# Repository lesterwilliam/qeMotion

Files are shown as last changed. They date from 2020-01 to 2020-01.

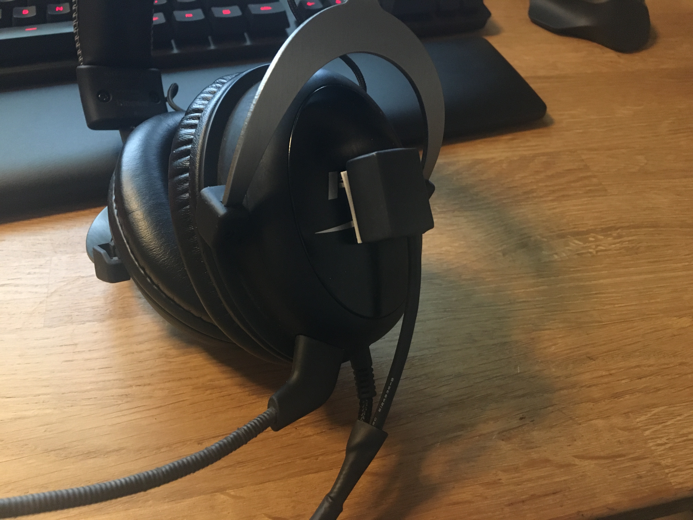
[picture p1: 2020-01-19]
media/Sensor/Sensor mounted 1.JPG

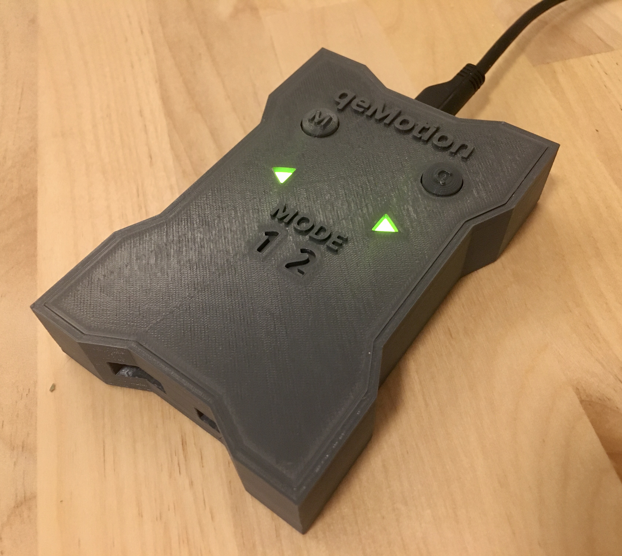
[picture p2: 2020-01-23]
media/Complete/qeMotion complete 1.JPG

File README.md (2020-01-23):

# qeMotion

## Introduction
This project originated from my need make leaning in first-person-shooter games easier. Games that enable you to lean around corners to peak or take a shot with giving the enemy the smallest possible target, like PlayerUnknown Battleground or Tom Clancy's Six Siege usually implemet leaning with the keyboard keys 'Q' and 'E'. While it is quite the obvious choice to use the keys close to the usual movement-keys 'W'/'A'/'S'/'D', it is quite hard to use if you need to crouch, move and lean at the same time. There just aren't enough fingers.
My idea to the problem was to implement a simple device that tracks my head motion to trigger and hold the respective lean movement.

## Hardware
I tried to keep stuff simple. The essential two parts for this project are the Arduino Pro Micro and an MPU6050 Gyro-/Accelerometer unit. You can use other Arduino boards, but it has to have USB support. The ATmega32u4 does that, which is found of the Arduino Leonardo too for example.
In my implementation are two buttons, two LED to show the virtual press of the 'Q'/'E' keys and four LEDs to show a mode. The LEDs are controlled via bipolar Transistors, either high- or low-side switches. This might not be of importance, I wasn't sure if the Arduino pins can deliver that much current. If you decide to use low-current LEDs you should be fine with driving them directly from the Arduino.
The MPU6050 sensor unit is fixed to the headset, while the Arduino sits on my desk. I went for this approach to minimize weight on my head. Since sensor and Arduino communicate via I2C, which is not meant to be used over such distances, I used an old USB cable which at least has some sort of shielding. Don't know if this was necessairy, but it seems to work perfectly with a cable length of 1.2m (4ft).

## Software
To make development easier and usage more versatile I've implemented multiple modes for the device. Only two of which are actually in use right now, one of which does exactly nothing, and the other is my first try at motion tracking (which works to some degree).
The usual loop() function calls subfunctions in defined time intervals, which can be tuned in the #defines.

This whole software is not nearly perfect nor finished. But I've tried to design it in a way it is the easiest to understand and modify to someones needs. If you struggle to understand it's structure and thoughts behind it, feel free to ask me anything. I'd be glad to help!

## Case
I've designed a 3d-printable case for the device. This may not suit you and your PCB layout, but I'll try to add some photos of my PCB for reference.
There is also a secondary case which doesn't really have to do anything with this sensor. But since my headset (HyperX Cloud 2) has this remote near where the Arduino will sit, I've designed a case that snaps those two together nicely (MAGNETS!!).

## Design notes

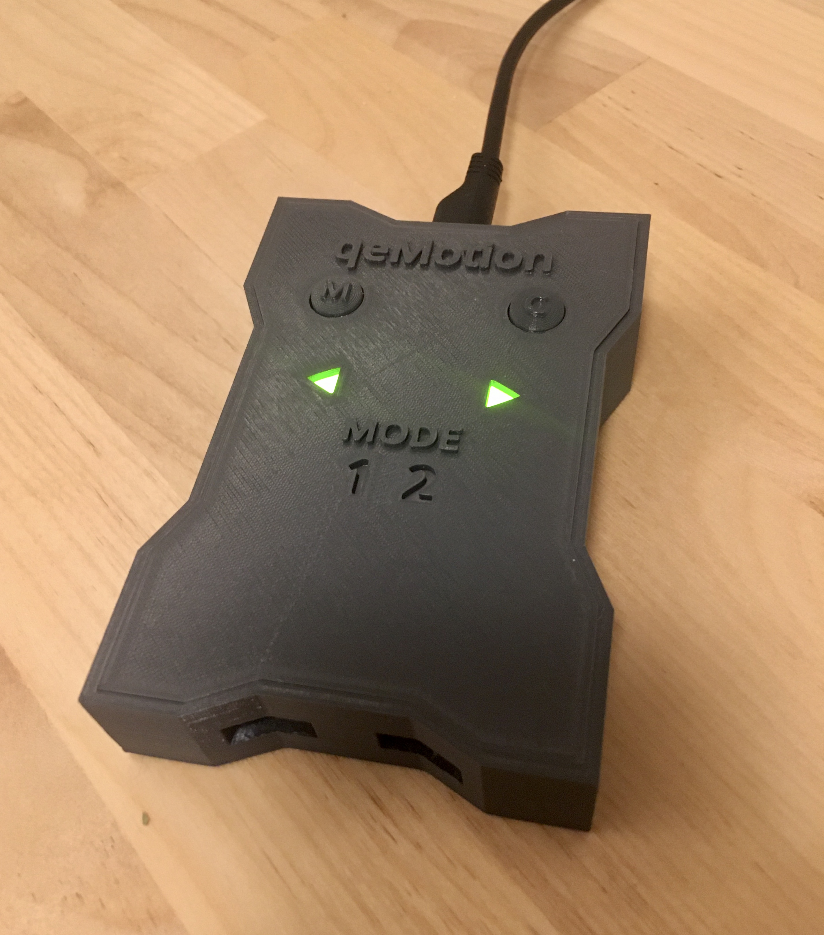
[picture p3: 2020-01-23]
media/Complete/qeMotion complete 2.JPG

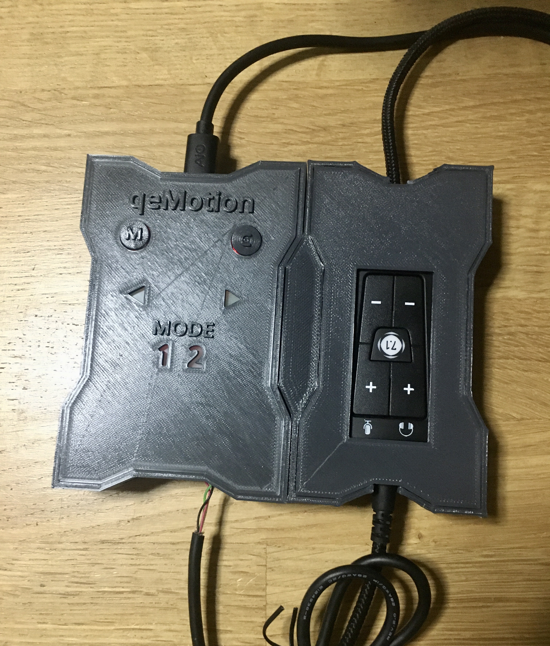
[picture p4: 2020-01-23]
media/Complete/qeMotion with HyperX Addon 4.JPG

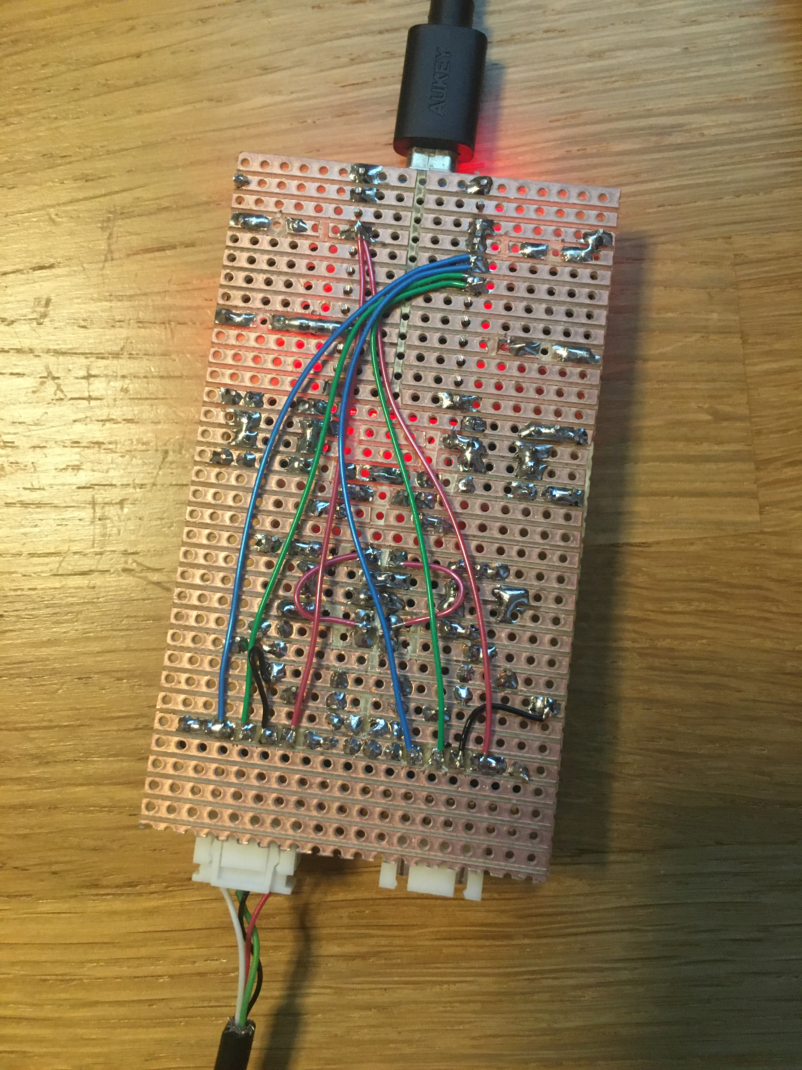
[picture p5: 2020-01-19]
media/PCB/PCB back.JPG

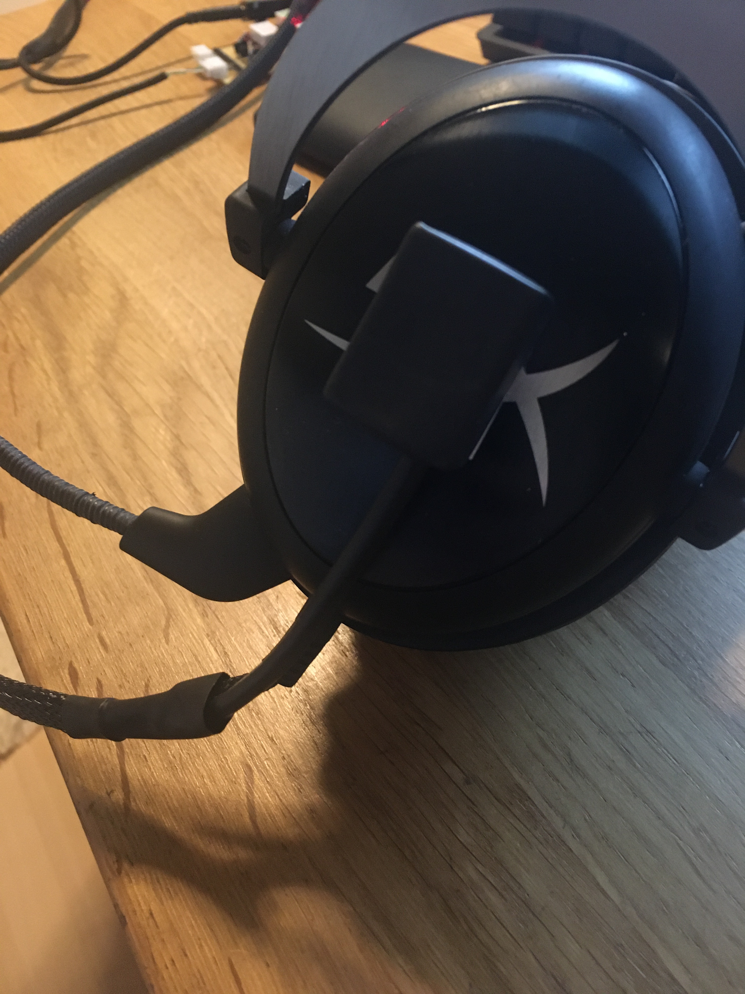
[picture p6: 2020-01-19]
media/Sensor/Sensor mounted 2.JPG

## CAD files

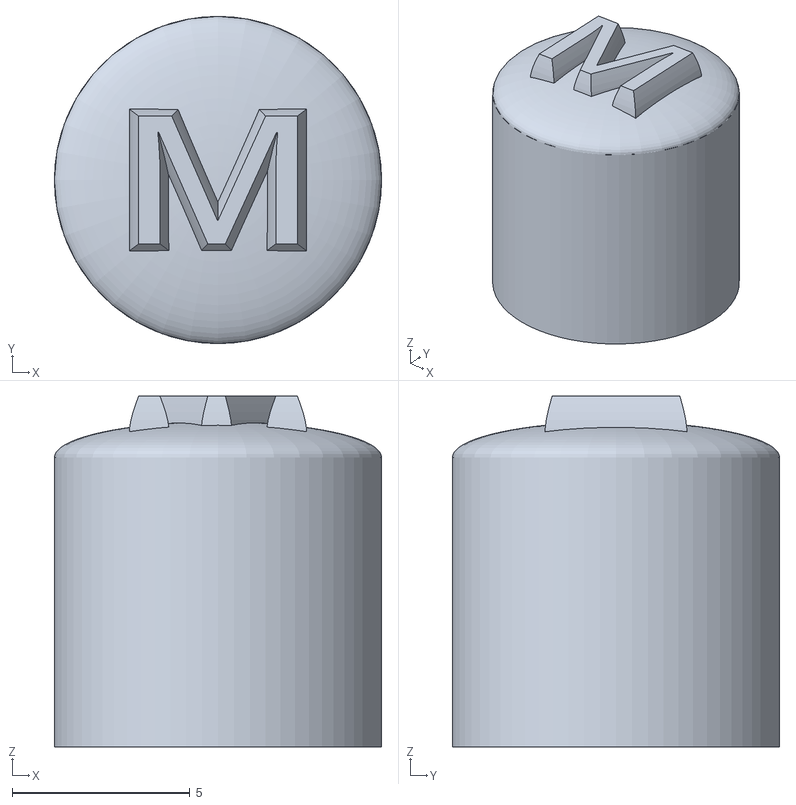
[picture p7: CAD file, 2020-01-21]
3D/Controller/qeMotion Button mode.stl
9.20 x 9.20 x 9.87

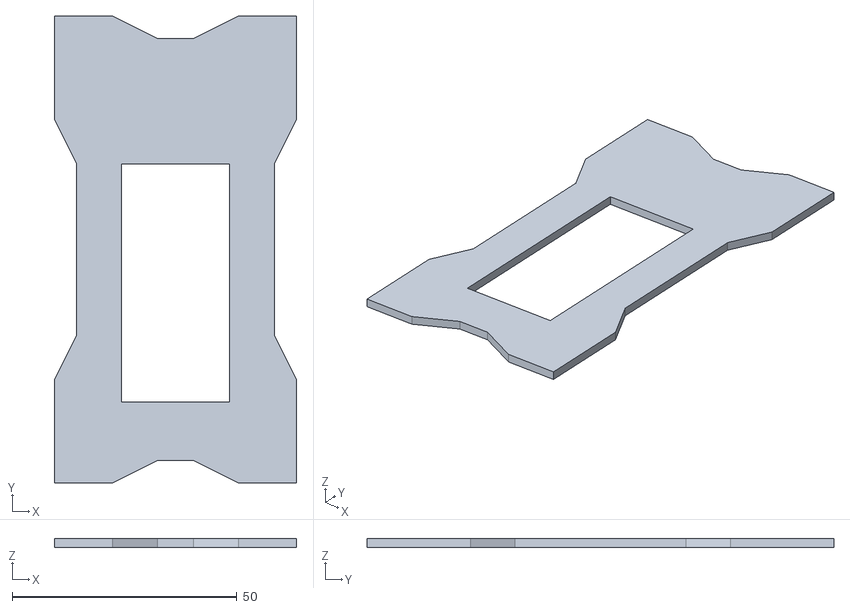
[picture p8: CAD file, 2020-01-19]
3D/HyperX Cloud 2 Headset Addon/qeMotion HyperX Cloud Addon upper.stl
54.0 x 104.0 x 2.00

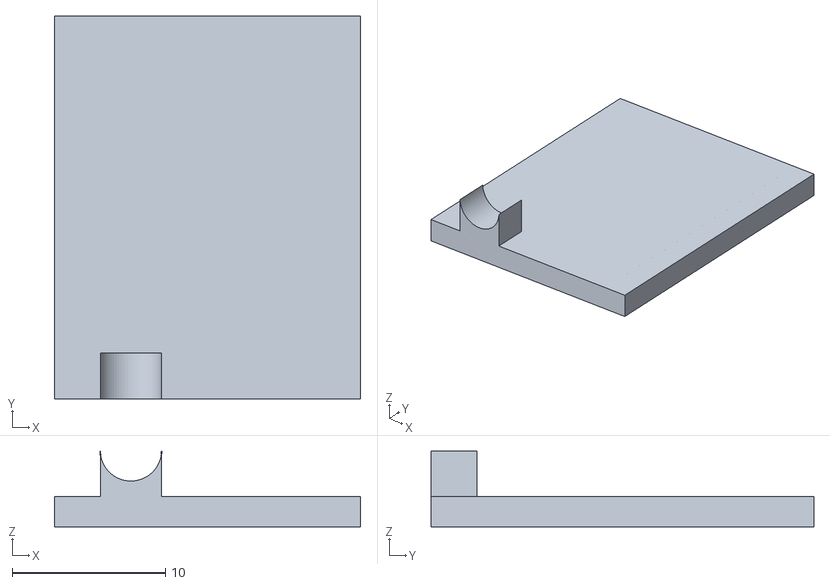
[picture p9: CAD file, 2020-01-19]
3D/Sensor/qeMotion Sensor lower.stl
20.0 x 25.0 x 4.96

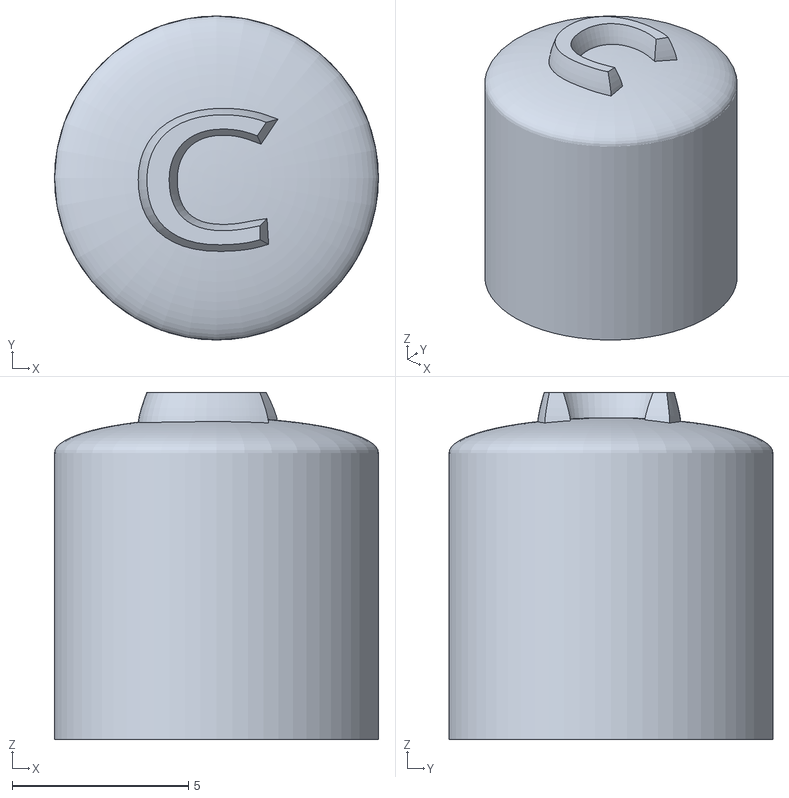
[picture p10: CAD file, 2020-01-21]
3D/Controller/qeMotion Button calibration.stl
9.20 x 9.20 x 9.87

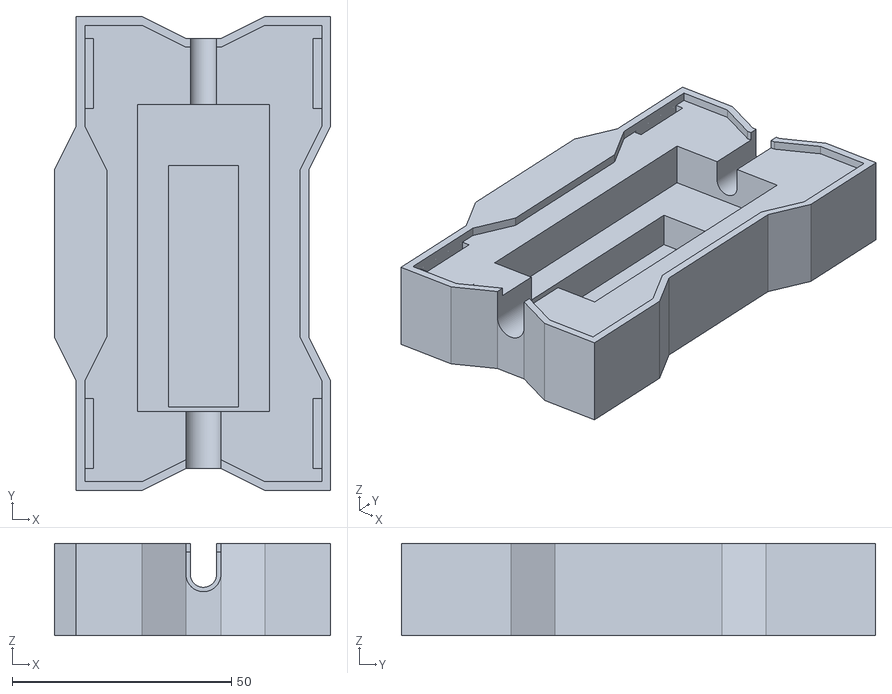
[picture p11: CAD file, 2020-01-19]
3D/HyperX Cloud 2 Headset Addon/qeMotion HyperX Cloud Addon lower.stl
63.0 x 108.0 x 21.0

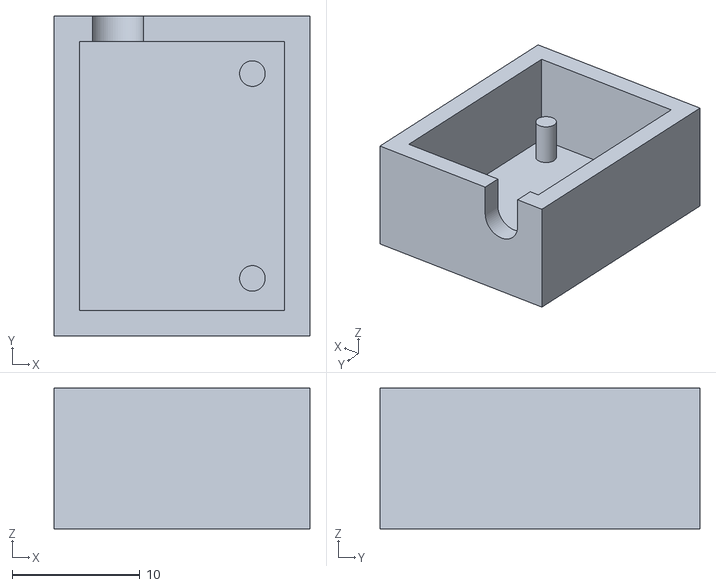
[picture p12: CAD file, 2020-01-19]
3D/Sensor/qeMotion Sensor upper.stl
20.0 x 25.0 x 11.0

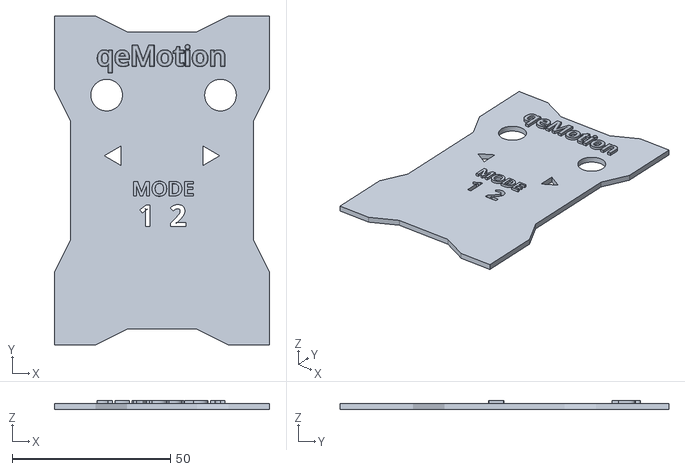
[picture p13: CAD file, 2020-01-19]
3D/Controller/qeMotion upper.stl
68.0 x 104.0 x 3.00

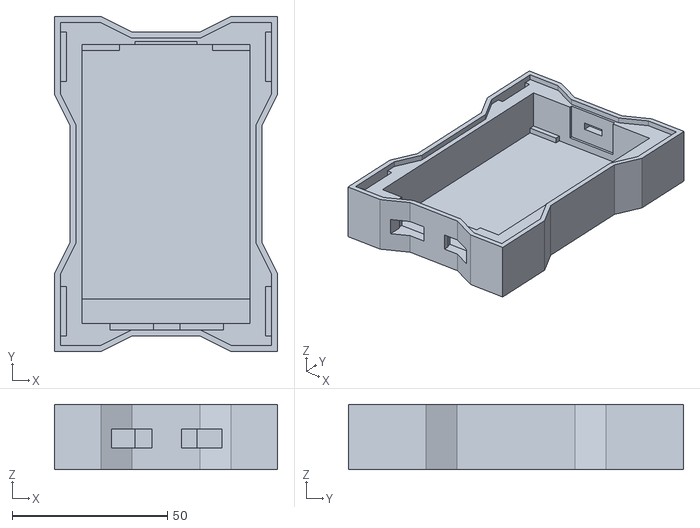
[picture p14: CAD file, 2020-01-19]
3D/Controller/qeMotion lower.stl
72.0 x 108.0 x 21.0

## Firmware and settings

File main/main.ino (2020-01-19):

// Inclusion of hardware libraries
#include <Wire.h>
#include <I2Cdev.h>
#include <MPU6050.h>
#include <Keyboard.h>

// Hardware pin definitions
#define LED_Q               9
#define LED_E               10
#define LED_STATUS_1        7
#define LED_STATUS_2        6
#define LED_STATUS_3        5
#define LED_STATUS_4        4
#define BUTTON_L            14
#define BUTTON_R            15

// Timing definitions
#define TRACKER_INTERVAL    10 // These values define how frequent those taskt are done (in ms)
#define MOTION_INTERVAL     50
#define KEYBOARD_INTERVAL   10
#define LED_INTERVAL        100
#define BUTTON_INTERVAL     10
#define TEST_INTERVAL       1000
#define TRACKING_DURATION   400
#define TRACKING_TICKS      (TRACKING_DURATION / TRACKER_INTERVAL)
#define MOTION_SENSITIVITY  35

unsigned long currentMillis = 0;
unsigned long tracker_previousMillis = 0;
unsigned long motion_previousMillis = 0;
unsigned long keyboard_previousMillis = 0;
unsigned long led_previousMillis = 0;
unsigned long button_previousMillis = 0;
unsigned long test_previousMillis = 0;

// System flags
unsigned char button_l_flag = 0;
unsigned char button_r_flag = 0;
unsigned char keyboard_hold_q = 0;
unsigned char keyboard_hold_e = 0;
unsigned char mode = 0; // 0 = disabled; 1 = qeButtons; 2 = qeMotion
unsigned char mpuConnected = 0;

// Motion tracking objects and data
MPU6050 mpu;
int16_t ax, ay, az, gx, gy, gz;
int vx[TRACKING_TICKS] = {0};
int vy[TRACKING_TICKS] = {0};
int vz[TRACKING_TICKS] = {0};
int trackerCounter = 0;

void hardwareTest(){
  digitalWrite(LED_E, HIGH);
  digitalWrite(LED_Q, LOW);
  delay(200);
  digitalWrite(LED_Q, HIGH);
  digitalWrite(LED_E, LOW);
  delay(200);
  digitalWrite(LED_E, HIGH);

  for(int i = 0; i < 5; i++){
    digitalWrite(LED_STATUS_1, HIGH);
    delay(50);
    digitalWrite(LED_STATUS_1, LOW);
    digitalWrite(LED_STATUS_2, HIGH);
    delay(50);
    digitalWrite(LED_STATUS_2, LOW);
    digitalWrite(LED_STATUS_3, HIGH);
    delay(50);
    digitalWrite(LED_STATUS_3, LOW);
    digitalWrite(LED_STATUS_4, HIGH);
    delay(50);
    digitalWrite(LED_STATUS_4, LOW);
    digitalWrite(LED_STATUS_3, HIGH);
    delay(50);
    digitalWrite(LED_STATUS_3, LOW);
    digitalWrite(LED_STATUS_2, HIGH);
    delay(50);
    digitalWrite(LED_STATUS_2, LOW);
  }
}

void setup(){
  Serial.begin(9600);
  Wire.begin();
  pinMode(LED_STATUS_4, OUTPUT);
  pinMode(LED_STATUS_3, OUTPUT);
  pinMode(LED_STATUS_2, OUTPUT);
  pinMode(LED_STATUS_1, OUTPUT);
  pinMode(LED_Q, OUTPUT);
  pinMode(LED_E, OUTPUT);
  pinMode(14, INPUT_PULLUP);
  pinMode(15, INPUT_PULLUP);
  
  digitalWrite(LED_Q, HIGH);
  digitalWrite(LED_E, HIGH);
  hardwareTest();
  
  mpu.initialize();
  if(!mpu.testConnection()) {
    mpuConnected = 0;
    noSensor();
  }else{
    mpuConnected = 1;
  }
  Keyboard.begin();
  delay(3000);
}

void noSensor(){
  for(int i = 0; i < 6; i++){
    digitalWrite(LED_Q, LOW);
    digitalWrite(LED_E, LOW);
    delay(500);
    digitalWrite(LED_E, HIGH);
    digitalWrite(LED_Q, HIGH);
  }
}

void tracker(){
  if(mpuConnected){
    mpu.getMotion6(&ax, &ay, &az, &gx, &gy, &gz);
    vx[trackerCounter] =  (gx + 1800) / 150;  // "+300" because the x axis of gyroscope give values about -350 while it's not moving. Change this value if you get something different using the TEST code, chacking if there are values far from zero.
    vy[trackerCounter] = -(gy -   30) / 150; // same here about "-100"
    vz[trackerCounter] = -(gz -   30) / 150; // same here about "-100"
    
    if(trackerCounter >= (TRACKING_TICKS -1)){
      trackerCounter = 0;
    }else{
      trackerCounter++;
    }
  }else{
    noSensor();
  }
}

void motion(){
  switch(mode){
    case 0:
      break;
      
    case 1:
      break;
      
    case 2:
      int avgVx = 0;
      for(int i = 0; i < TRACKING_TICKS; i++){
        avgVx += vx[i];
      }
      avgVx = (int)(avgVx / TRACKING_TICKS);
      Serial.println(avgVx);
    
      if(avgVx < - MOTION_SENSITIVITY){ // movement to left
        if(keyboard_hold_e){
          keyboard_hold_q = 0;
          keyboard_hold_e = 0;
        }else{
          keyboard_hold_q = 1;
          keyboard_hold_e = 0;
        }
        
        for(int i = 0; i < TRACKING_TICKS; i++){
          vx[i] = 0;
        }
      }
      
      if(avgVx > MOTION_SENSITIVITY){ // movement to right
        if(keyboard_hold_q){
          keyboard_hold_q = 0;
          keyboard_hold_e = 0;
        }else{
          keyboard_hold_q = 0;
          keyboard_hold_e = 1;
        }
        for(int i = 0; i < TRACKING_TICKS; i++){
          vx[i] = 0;
        }
      }
      break;
      
    default:
      break;
  }
}

void keyboard(){
  if(keyboard_hold_q){
    Keyboard.press('q');
  }else{
    Keyboard.release('q');
  }

  if(keyboard_hold_e){
    Keyboard.press('e');
  }else{
    Keyboard.release('e');
  }
}

void led(){
  switch(mode){
    case 0: // disabled
      digitalWrite(LED_STATUS_1, LOW);
      digitalWrite(LED_STATUS_2, LOW);
      digitalWrite(LED_STATUS_3, LOW);
      digitalWrite(LED_STATUS_4, LOW);
      break;
      
    case 1: // qeButtons
      digitalWrite(LED_STATUS_1, HIGH);
      digitalWrite(LED_STATUS_2, HIGH);
      digitalWrite(LED_STATUS_3, LOW);
      digitalWrite(LED_STATUS_4, LOW);

      if(keyboard_hold_e){
        digitalWrite(LED_E, LOW);
      }else{
        digitalWrite(LED_E, HIGH);
      }
      break;
      
    case 2: // qeMotion
      if(keyboard_hold_q){
        digitalWrite(LED_Q, LOW);
      }else{
        digitalWrite(LED_Q, HIGH);
      }
      
      if(keyboard_hold_e){
        digitalWrite(LED_E, LOW);
      }else{
        digitalWrite(LED_E, HIGH);
      }
      
      digitalWrite(LED_STATUS_1, LOW);
      digitalWrite(LED_STATUS_2, LOW);
      digitalWrite(LED_STATUS_3, HIGH);
      digitalWrite(LED_STATUS_4, HIGH);
      break;

    default:
      break;
  }


}

void button(){
  // Button left
  if(!digitalRead(BUTTON_L) && !button_l_flag){
    button_l_flag = 1;
    if(mode <= 1){
      mode++;
    }else{
      mode = 0;
    }
    keyboard_hold_q = 0;
    keyboard_hold_e = 0;
    Serial.println(mode);
  }
  if(digitalRead(BUTTON_L)){
    button_l_flag = 0;
  }

  // Button right
  switch(mode){
    case 0: // disabled
      break;
      
    case 1: // qeButton
      if(!digitalRead(BUTTON_R) && !button_r_flag){
        button_r_flag = 1;
        keyboard_hold_e = 1;
      }
      if(digitalRead(BUTTON_R)){
        button_r_flag = 0;
        keyboard_hold_e = 0;
      }
      break;
      
    case 2: // qeMotion
      if(!digitalRead(BUTTON_R) && !button_r_flag){
        button_r_flag = 1;
        keyboard_hold_e = 0;
        keyboard_hold_q = 0;
      }
      if(digitalRead(BUTTON_R)){
        button_r_flag = 0;
      }
      break;
      
    default:
      break;
  }
}

void loop(){
  currentMillis = millis();
  if (currentMillis - tracker_previousMillis >= TRACKER_INTERVAL) {
    tracker_previousMillis = currentMillis;
    tracker();
  }
  
  if (currentMillis - motion_previousMillis >= MOTION_INTERVAL) {
    motion_previousMillis = currentMillis;
    motion();
  }
  
  if (currentMillis - keyboard_previousMillis >= KEYBOARD_INTERVAL) {
    keyboard_previousMillis = currentMillis;
    keyboard();
  }
  
  if (currentMillis - led_previousMillis >= LED_INTERVAL) {
    led_previousMillis = currentMillis;
    led();
  }
  
  if(currentMillis - button_previousMillis >= BUTTON_INTERVAL){
    button_previousMillis = currentMillis;
    button();
  }
  
  if(currentMillis - test_previousMillis >= TEST_INTERVAL){
    test_previousMillis = currentMillis;
  }
}

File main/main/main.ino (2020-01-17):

#include <Wire.h>
#include <I2Cdev.h>
#include <MPU6050.h>
#include <Keyboard.h>

#define TRACKER_INTERVAL 10
#define KEYBOARD_INTERVAL 10
#define LED_INTERVAL 10
#define TRACKING_DURATION 500
#define TRACKING_TICKS (TRACKING_DURATION / TRACKER_INTERVAL)

unsigned long currentMillis = 0;

unsigned long tracker_previousMillis = 0;
unsigned long keyboard_previousMillis = 0;
unsigned long led_previousMillis = 0;

MPU6050 mpu;
int16_t ax, ay, az, gx, gy, gz;
int vx[TRACKING_TICKS] = {0};
int vy[TRACKING_TICKS] = {0};
int vz[TRACKING_TICKS] = {0};
int trackerCounter = 0;

void setup() {
  Serial.begin(9600);
  Wire.begin();
  pinMode(4, OUTPUT);
  pinMode(5, OUTPUT);
  pinMode(6, OUTPUT);
  pinMode(7, OUTPUT);
  pinMode(9, OUTPUT);
  pinMode(10, OUTPUT);
  pinMode(14, INPUT_PULLUP);
  pinMode(15, INPUT_PULLUP);
  mpu.initialize();
  if (!mpu.testConnection()) { while (1); }
  Keyboard.begin();
  delay(5000);
}

void tracker(){
  mpu.getMotion6(&ax, &ay, &az, &gx, &gy, &gz);
  vx[trackerCounter] =  (gx + 1800) / 150;  // "+300" because the x axis of gyroscope give values about -350 while it's not moving. Change this value if you get something different using the TEST code, chacking if there are values far from zero.
  vy[trackerCounter] = -(gy -   30) / 150; // same here about "-100"
  vz[trackerCounter] = -(gz -   30) / 150; // same here about "-100"

  /*Serial.print("gx = ");
  Serial.print(gx);
  Serial.print("gy = ");
  Serial.print(gy);
  Serial.print(" | gz = ");
  Serial.print(gz);
  */
  Serial.print("        | X = ");
  Serial.print(vx[trackerCounter]);
  Serial.print(" | Y = ");
  Serial.print(vy[trackerCounter]);
  Serial.print(" | Z = ");
  Serial.println(vz[trackerCounter]);

  if(trackerCounter >= (TRACKING_TICKS -1)){
    trackerCounter = 0;
  }else{
    trackerCounter++;
  }
}

void keyboard(){
}

void led(){
}


void loop() {
  currentMillis = millis();
  if (currentMillis - tracker_previousMillis >= TRACKER_INTERVAL) {
    tracker_previousMillis = currentMillis;
    tracker();
  }
  if (currentMillis - keyboard_previousMillis >= KEYBOARD_INTERVAL) {
    keyboard_previousMillis = currentMillis;
    keyboard();
  }
  if (currentMillis - led_previousMillis >= LED_INTERVAL) {
    led_previousMillis = currentMillis;
    led();
  }
  
  //Keyboard.print("test");
  //delay(1000);
  //Keyboard.press('e');
  //delay(2000);
  //Keyboard.releaseAll();
  //delay(1000000);
}

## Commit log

2020-01-08 Library for MPU6050
    https://maker.pro/arduino/tutorial/how-to-interface-arduino-and-the-mpu-6050-sensor
2020-01-18 First fully working prototype
    Motion detection needs some refinement to be done on.
2020-01-19 Added 3d parts
    [qeMotion HyperX Cloud Addon lower.stl, qeMotion HyperX Cloud Addon upper.stl, qeMotion lower.stl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]
